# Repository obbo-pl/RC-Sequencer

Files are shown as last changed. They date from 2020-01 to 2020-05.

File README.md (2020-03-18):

# RC-Sequencer
  The purpose of the system is to switch on several electrical circuits using one RC channel. The change of state takes place according to programmed sequences. 

##### Main features:
- 4 output circuits,
- 8 programmed sequences,
- sequence selection by jumper configuration,
- maximum length of programmed sequence 15 (ATtiny24), 31 (ATtiny44), 63 (ATtiny84),
- the ability to change the sequence in both directions,
- maximum output circuit current: 1A,
- maximum voltage for output circuits: 20V.

### Hardware & Firmware.
These sections covers info on building sample hardware, including schematics, PCBs, and the corresponding firmware.

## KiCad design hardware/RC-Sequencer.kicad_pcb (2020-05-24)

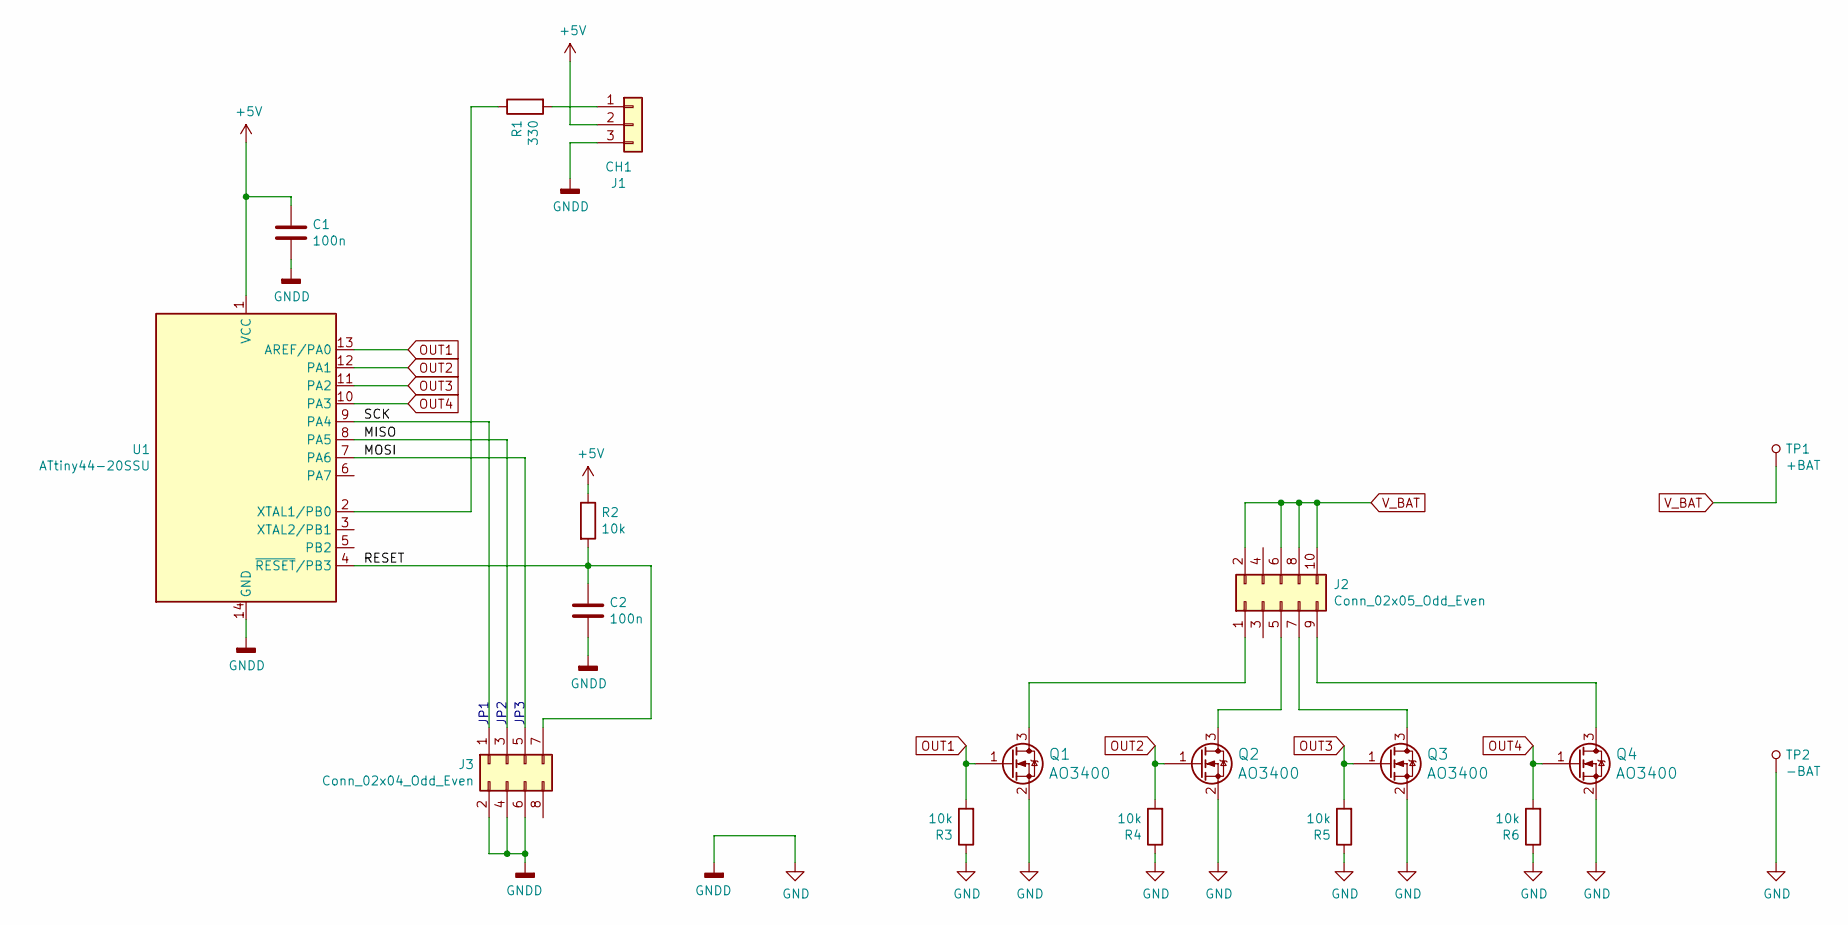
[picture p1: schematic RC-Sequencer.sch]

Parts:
C1, C2: 100n; C_0805K
J1: CH1; PinHeader_1x03_P2.54mm_Horizontal_PAD_noPinSilk
J2: Conn_02x05_Odd_Even; PinHead_2x05_P2.54mm_SMD_Horizontal_Edge
J3: Conn_02x04_Odd_Even; PinHead_2x04_P2.54mm_SMD_Horizontal_Edge
Q1, Q2, Q3, Q4: AO3400; SOT-23_HandSoldering
R1: 330; R_0805K
R2, R3, R4, R5, R6: 10k; R_0805K
TP1: +BAT; SolderWirePad_single_SMD_3x8mm
TP2: -BAT; SolderWirePad_single_SMD_3x8mm
U1: ATtiny44-20SSU; SOIC-14_3.9x8.7mm_P1.27mm

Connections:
+5V: C1.1, J1.2, R2.1, U1.1 (VCC)
/MISO: J3.3, U1.8 (PA5)
/MOSI: J3.5, U1.7 (PA6)
/RESET: C2.1, J3.7, R2.2, U1.4 (~RESET~/PB3)
/SCK: J3.1, U1.9 (PA4)
GND: C1.2, C2.2, J1.3, J3.2, J3.4, J3.6, Q1.2 (S), Q2.2 (S), Q3.2 (S), Q4.2 (S), R3.1, R4.1, R5.1, R6.1, TP2.1, U1.14 (GND)
unnamed: J1.1, R1.2
unnamed: J2.1, Q1.3 (D)
unnamed: J2.5, Q2.3 (D)
unnamed: J2.7, Q3.3 (D)
unnamed: J2.9, Q4.3 (D)
unnamed: R1.1, U1.2 (XTAL1/PB0)
OUT1: Q1.1 (G), R3.2, U1.13 (AREF/PA0)
OUT2: Q2.1 (G), R4.2, U1.12 (PA1)
OUT3: Q3.1 (G), R5.2, U1.11 (PA2)
OUT4: Q4.1 (G), R6.2, U1.10 (PA3)
V_BAT: J2.2, J2.6, J2.8, J2.10, TP1.1

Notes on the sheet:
JP1
JP2
JP3

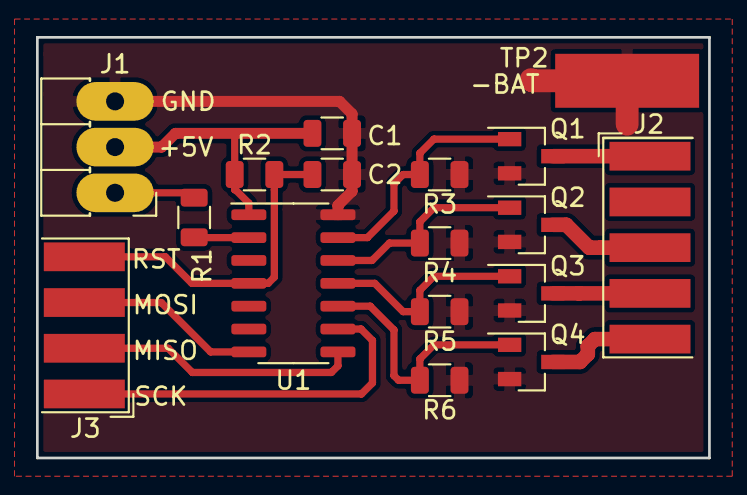
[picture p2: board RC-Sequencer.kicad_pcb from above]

Board: 2 copper layers, 37.3 x 23.4 mm, 18 parts (1 on the bottom side), 17 nets.

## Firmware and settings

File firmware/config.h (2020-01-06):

/*
 * config.h
 *
 * Created: 30.08.2019 12:09:12
 * Atmel Studio 6 (Version: 6.2.1563 - Service Pack 2)
 * AVR/GNU C Compiler : 4.8.1
 *  Author: Krzysztof Markiewicz
 *  www.obbo.pl
 *
 * This program is distributed under the terms of the GNU General Public License
 */ 


#ifndef CONFIG_H_
#define CONFIG_H_


// OUT port
#define CONFIG_OUT1_PORT		A
#define CONFIG_OUT1_PIN			0

#define CONFIG_OUT2_PORT		A
#define CONFIG_OUT2_PIN			1

#define CONFIG_OUT3_PORT		A
#define CONFIG_OUT3_PIN			2

#define CONFIG_OUT4_PORT		A
#define CONFIG_OUT4_PIN			3


// Configuration pinhead (CFG1 - CFG3)
#define CONFIG_CFG1_PORT		A
#define	CONFIG_CFG1_PIN			4

#define CONFIG_CFG2_PORT		A
#define	CONFIG_CFG2_PIN			5

#define CONFIG_CFG3_PORT		A
#define	CONFIG_CFG3_PIN			6


// Channel signal (CH1)
#define CONFIG_CH1_PORT			B
#define CONFIG_CH1_PIN			0


#endif /* CONFIG_H_ */

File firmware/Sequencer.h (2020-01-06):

/*
 * Sequencer.h
 *
 * Created: 2020-01-04 20:42:43
 * Atmel Studio 6 (Version: 6.2.1563 - Service Pack 2)
 * AVR/GNU C Compiler : 4.8.1
 *  Author: Krzysztof Markiewicz
 *  www.obbo.pl
 *
 * This program is distributed under the terms of the GNU General Public License
 */ 


#ifndef SEQUENCER_H_
#define SEQUENCER_H_

#include <avr/io.h>
#include <avr/eeprom.h>
#include <avr/pgmspace.h>
#include "config.h"
#include "macro.h"


// I/O port for motor bridge
#define OUT_OUT1					(glue2(DDR, CONFIG_OUT1_PORT) |= (1 << glue3(DD, CONFIG_OUT1_PORT, CONFIG_OUT1_PIN)))
#define SET_OUT1					(glue2(PORT, CONFIG_OUT1_PORT) |= (1 << glue3(P, CONFIG_OUT1_PORT, CONFIG_OUT1_PIN)))
#define CLR_OUT1					(glue2(PORT, CONFIG_OUT1_PORT) &= ~(1 << glue3(P, CONFIG_OUT1_PORT, CONFIG_OUT1_PIN)))

#define OUT_OUT2					(glue2(DDR, CONFIG_OUT2_PORT) |= (1 << glue3(DD, CONFIG_OUT2_PORT, CONFIG_OUT2_PIN)))
#define SET_OUT2					(glue2(PORT, CONFIG_OUT2_PORT) |= (1 << glue3(P, CONFIG_OUT2_PORT, CONFIG_OUT2_PIN)))
#define CLR_OUT2					(glue2(PORT, CONFIG_OUT2_PORT) &= ~(1 << glue3(P, CONFIG_OUT2_PORT, CONFIG_OUT2_PIN)))

#define OUT_OUT3					(glue2(DDR, CONFIG_OUT3_PORT) |= (1 << glue3(DD, CONFIG_OUT3_PORT, CONFIG_OUT3_PIN)))
#define SET_OUT3					(glue2(PORT, CONFIG_OUT3_PORT) |= (1 << glue3(P, CONFIG_OUT3_PORT, CONFIG_OUT3_PIN)))
#define CLR_OUT3					(glue2(PORT, CONFIG_OUT3_PORT) &= ~(1 << glue3(P, CONFIG_OUT3_PORT, CONFIG_OUT3_PIN)))

#define OUT_OUT4					(glue2(DDR, CONFIG_OUT4_PORT) |= (1 << glue3(DD, CONFIG_OUT4_PORT, CONFIG_OUT4_PIN)))
#define SET_OUT4					(glue2(PORT, CONFIG_OUT4_PORT) |= (1 << glue3(P, CONFIG_OUT4_PORT, CONFIG_OUT4_PIN)))
#define CLR_OUT4					(glue2(PORT, CONFIG_OUT4_PORT) &= ~(1 << glue3(P, CONFIG_OUT4_PORT, CONFIG_OUT4_PIN)))


// Configuration pinhead (CFG1 - CFG3)
#define PULL_CFG1					(glue2(PORT, CONFIG_CFG1_PORT) |= (1 << glue3(P, CONFIG_CFG1_PORT, CONFIG_CFG1_PIN)))
#define READ_CFG1					((glue2(PIN, CONFIG_CFG1_PORT) >> glue3(P, CONFIG_CFG1_PORT, CONFIG_CFG1_PIN)) & 0x01)

#define PULL_CFG2					(glue2(PORT, CONFIG_CFG2_PORT) |= (1 << glue3(P, CONFIG_CFG2_PORT, CONFIG_CFG2_PIN)))
#define READ_CFG2					((glue2(PIN, CONFIG_CFG2_PORT) >> glue3(P, CONFIG_CFG2_PORT, CONFIG_CFG2_PIN)) & 0x01)

#define PULL_CFG3					(glue2(PORT, CONFIG_CFG3_PORT) |= (1 << glue3(P, CONFIG_CFG3_PORT, CONFIG_CFG3_PIN)))
#define READ_CFG3					((glue2(PIN, CONFIG_CFG3_PORT) >> glue3(P, CONFIG_CFG3_PORT, CONFIG_CFG3_PIN)) & 0x01)


// Channel signal (CH1)
#define PULL_CHANNEL1				(glue2(PORT, CONFIG_CH1_PORT) |= (1 << glue3(P, CONFIG_CH1_PORT, CONFIG_CH1_PIN)))
#define READ_CHANNEL1				((glue2(PIN, CONFIG_CH1_PORT) >> glue3(P, CONFIG_CH1_PORT, CONFIG_CH1_PIN)) & 0x01)

#define TIMER_COMMON_OVF_MS			(8)
#define RECALCULATE_INTERVAL_MS		(20)
#define SIGNAL_LOST_TIMEOUT_MS		(500)
#define CHANNEL_FILTER_LENGTH		(2)
#if (defined(__AVR_ATtiny24__) || defined(__AVR_ATtiny24A__))
	#define SEQUENCE_LENGTH			(4)
	#define EEMEM_SIZE				(128)
#elif (defined(__AVR_ATtiny44__) || defined(__AVR_ATtiny44A__))
	#define SEQUENCE_LENGTH			(5)
	#define EEMEM_SIZE				(256)
#elif (defined(__AVR_ATtiny84__) || defined(__AVR_ATtiny84A__))
	#define SEQUENCE_LENGTH			(6)
	#define EEMEM_SIZE				(512)
#endif

#define RECOVERY_DELAY_PL			(50)
#define ACCEPTED_ERRORS				(2)
#if (RECOVERY_DELAY_PL * ACCEPTED_ERRORS) >= 32767
#error "Decrease RECOVERY_DELAY_PL or ACCEPTED_ERRORS"
#endif

// Sanwa VG6DR
#define CHANNEL_PULSE_MAXIMUM		(250)
#define CHANNEL_PULSE_MINIMUM		(125)
#define CHANNEL_PULSE_NEUTRAL		((CHANNEL_PULSE_MAXIMUM + CHANNEL_PULSE_MINIMUM) / 2)
#define CHANNEL_PULSE_UP			((CHANNEL_PULSE_MAXIMUM + CHANNEL_PULSE_NEUTRAL) / 2)
#define CHANNEL_PULSE_DOWN			((CHANNEL_PULSE_MINIMUM + CHANNEL_PULSE_NEUTRAL) / 2)
#define CHANNEL_PULSE_ERROR			(5)

#define CHANNEL_PULSE_POSITIVE
#ifdef CHANNEL_PULSE_POSITIVE
#define CHANNEL_LEVEL_ACTIVE	(1)
#else
#define CHANNEL_LEVEL_ACTIVE	(0)
#endif

enum {
	OUT1_bp,
	OUT2_bp,
	OUT3_bp,
	OUT4_bp
};

enum {
	JUMPER_JP1_bp,
	JUMPER_JP2_bp,
	JUMPER_JP3_bp
};

enum {
	ERROR_TIMER_OVERLOAD_bp,
	ERROR_CHANNEL_OVERRANGE_bp,
	ERROR_CHANNEL_LOST_bp
};


#endif /* SEQUENCER_H_ */
